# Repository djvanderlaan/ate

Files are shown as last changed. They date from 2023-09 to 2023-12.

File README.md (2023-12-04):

A⋅TE Portable Computers and Keyboards
========================================================

A⋅TE⋅B1
----------------------------------------------------

The [A⋅TE⋅B1](b1/) is an 3d-printed ortholinear keyboard with a
statisticians/programmers layout. The files are released under a [CC BY-SA
license](https://creativecommons.org/licenses/by-sa/4.0/).

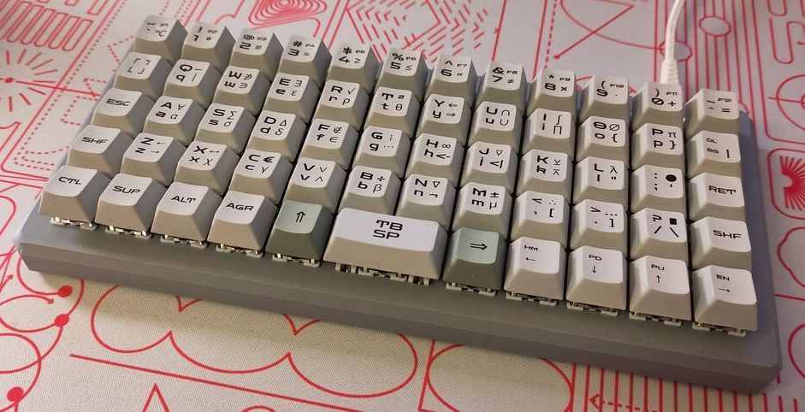
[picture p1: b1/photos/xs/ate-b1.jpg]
Photo of ATE-B1 keyboard


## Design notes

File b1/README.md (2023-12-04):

A⋅TE⋅B1 ortholinear keyboard
=====================================================

The [A⋅TE⋅B1](b1/) is an 3d-printed ortholinear keyboard with a
programmers/statisticians layout. The files are released under a [CC BY-SA
license](https://creativecommons.org/licenses/by-sa/4.0/).

Photo of ATE-B1 keyboard

Instructions
---------------------------------------------------------

Parts needed:

- 3d prints of the case and bottom
- Pro Micro controller. This build used a [Sparkfun Qwiic Pro Micro USB
  C](https://www.sparkfun.com/products/15795)
- 59 MX Switches and 2 stabilisers. This build used Gateron Keychron G Pro
  Yellow switches.
- 59 keycaps of which one 2 width keycap. In the build above existing keycaps
  were painted and labelled.
- 59 1N4148 diodes.
- 4 M2 screw inserts and 4 M2x8mm screws.

Tools needed:

- A soldering iron
- Wire stripper
- Some electric wire. For the columns solid core wire was used. To connect the
  rows and columns tot the controller stranded wire was used.

### Printing

The 3D print files are in the `stl/` directory. Both can be printed without
supports. The case should be printed upside down. The bottom bottom side down.
Supports are not needed. After printing two vertical supports in the slot that
holds the controller need to be removed (these are needed to be able to print
without supports). This can be done using an exacto knife and some prying. The
files are designed to fit a Prusa MK3s. 

Below are some photos of the case:

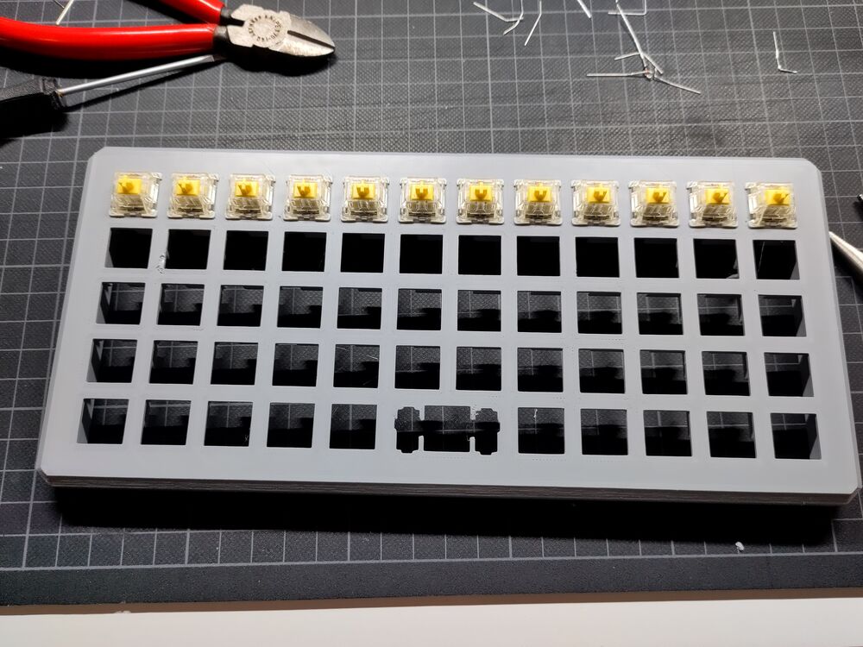
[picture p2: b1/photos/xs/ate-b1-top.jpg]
Photo of the top of the case with a few switches mounted


Photo of the bottom of the case with a few switches mounted

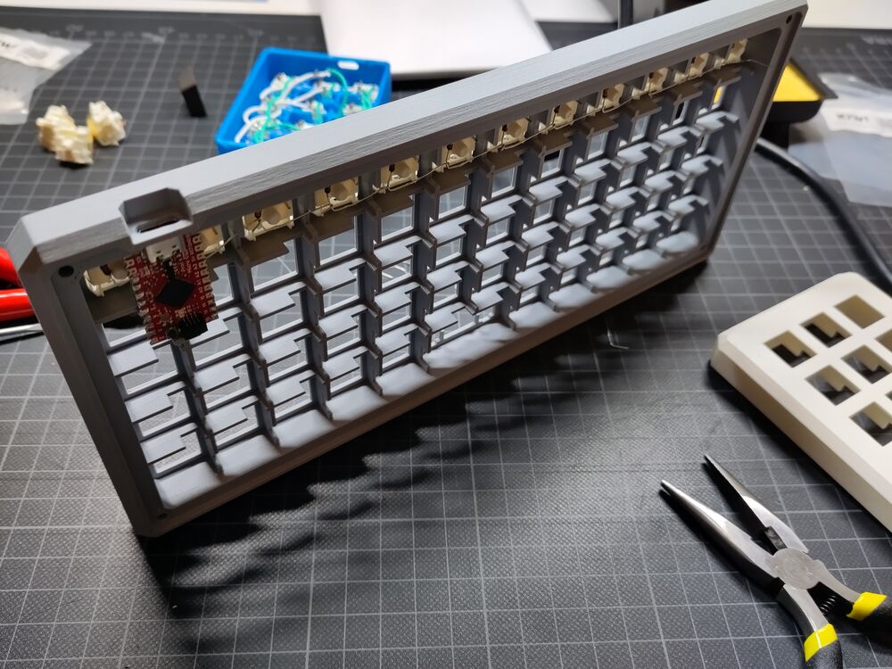
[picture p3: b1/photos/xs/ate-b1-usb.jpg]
Photo of the back of the case with the USB port


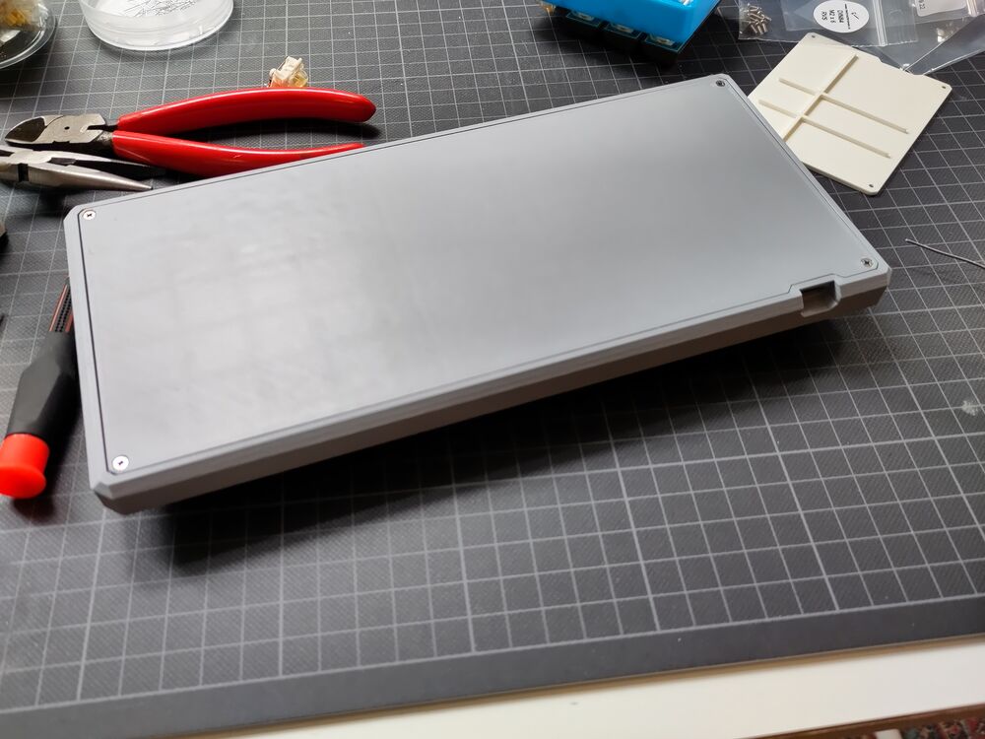
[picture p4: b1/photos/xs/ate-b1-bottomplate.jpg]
Photo of the back of the bottom plate


### Soldering

For general instructions see [A Complete Guide to Building a Hand-Wired Keyboard
by Ben
Chapman](https://www.crackedthecode.co/a-complete-guide-to-building-a-hand-wired-keyboard/) and
[the QMK guide on hand-wiring](https://docs.qmk.fm/#/hand_wire).  Below are
specific instructions for reproducing the build above and a picture of the
result:

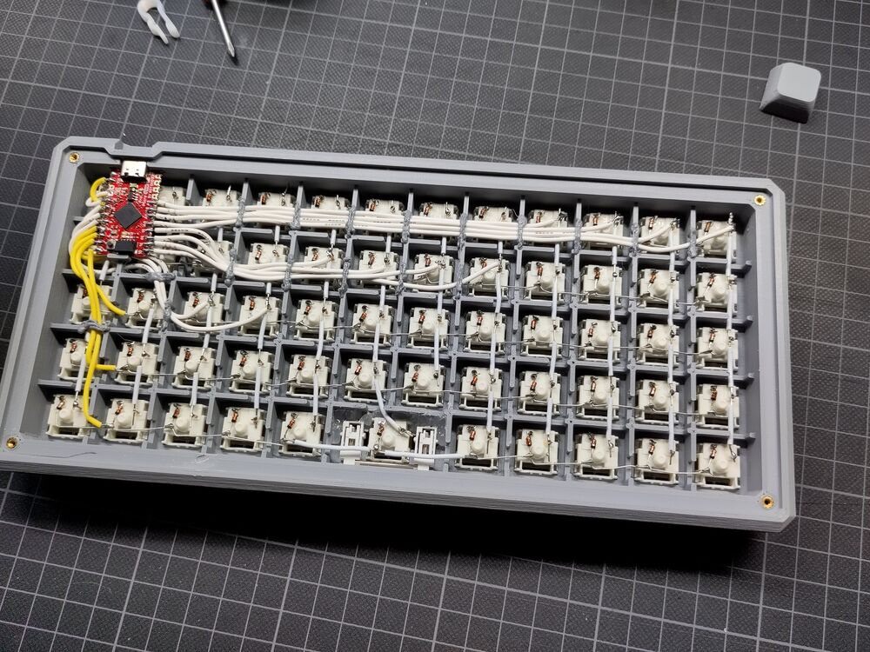
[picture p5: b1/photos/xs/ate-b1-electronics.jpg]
Photo of soldered electronics of the ATE-B1 keyboard


- For the rows the legs of the diodes were bent around each other and soldered
  together.
- Note that the spacebar is connected to column 6 (starting from 0). 
- For the columns an insulated wire was used where the insulation was removed at
  the points where it needed to be soldered to the switches. The easiest way to
  do this is to cut the insulation using a wire stripper and then push the
  insulation down the wire.

*TODO: wiring scheme for the controller*

### Programming the controller

First, follow [the instructions](https://docs.qmk.fm/#/newbs_getting_started) to
set up QMK. The git repository contains the keyboard configuration for the
A⋅TE⋅B1 under `qmk/`. Copy the contents of this directory to the
`keyboards/` directory under QMK or make a symbolic link (under linux).

Note the code assumes that the controller is wired as above and that the same
controller is used. If that is not the case the configuration has to be modified
to reflect the differences.

You should now be able to do:
```
qmk compile -kb ate_b1 -km default
```

Should this work you can do
```
qmk flash -kb ate_b1 -km default
```
to flash the controller. Follow the onscreen instructions. To get the controller
into flash mode you will have to press the reset button one the controller twice
in quick succession.

And then the keyboard should work. 

### Key caps

For the key caps of this build existing key caps were used. The were given a
thorough sanding with 280 grit sand paper. The two coats of gray primer (Vallejo
airbrush primer) and two coats of silver gray (Vallejo) using a air brush. The
labels were printed on 12µm transparent water slide decal paper (svg file is in
the repo). Some tips for this: use rounded corners and use a small stiff flat
brush to smoothen the decal on the key cap. After that the keys were varnished
using 4 layers of satin varnish (Vallejo).

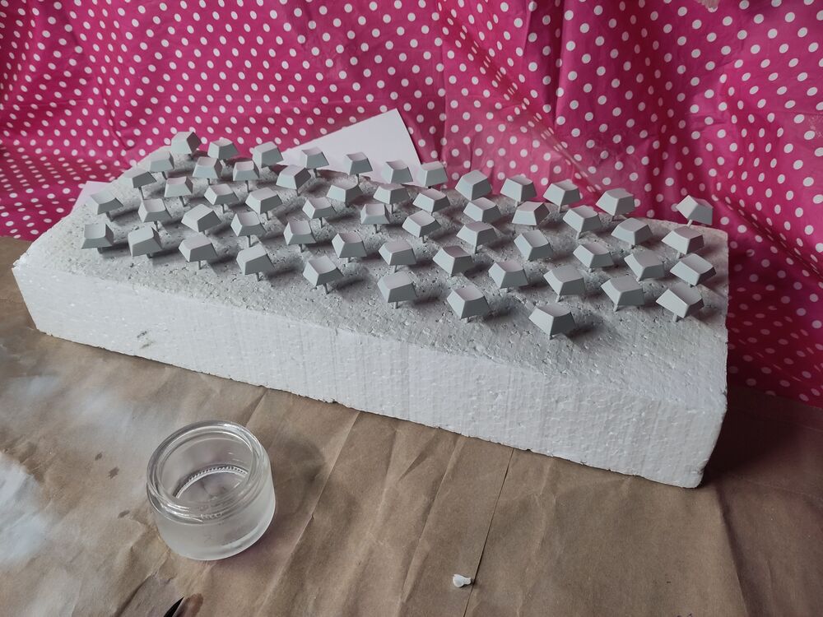
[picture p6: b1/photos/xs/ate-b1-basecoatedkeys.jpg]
Photo key caps with a base coat


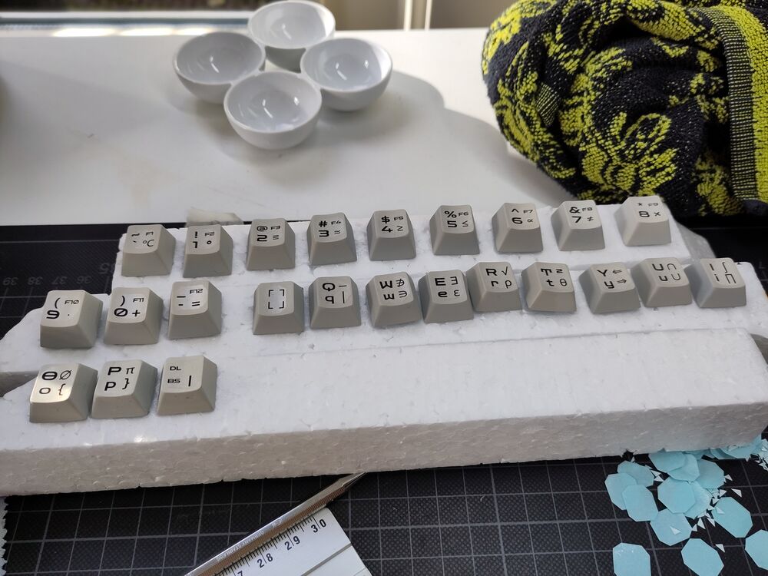
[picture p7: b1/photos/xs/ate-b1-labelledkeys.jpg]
Photo key caps with a labels


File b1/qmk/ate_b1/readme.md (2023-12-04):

# ate-b1

ate_b1

*A short description of the keyboard/project*

* Keyboard Maintainer: [djvanderlaan](https://github.com/djvanderlaan)
* Hardware Supported: *The PCBs, controllers supported*
* Hardware Availability: *Links to where you can find this hardware*

Make example for this keyboard (after setting up your build environment):

    make ate_b1:default

Flashing example for this keyboard:

    make ate_b1:default:flash

See the [build environment setup](https://docs.qmk.fm/#/getting_started_build_tools) and the [make instructions](https://docs.qmk.fm/#/getting_started_make_guide) for more information. Brand new to QMK? Start with our [Complete Newbs Guide](https://docs.qmk.fm/#/newbs).

## Bootloader

Enter the bootloader in 3 ways:

* **Bootmagic reset**: Hold down the key at (0,0) in the matrix (usually the top left key or Escape) and plug in the keyboard
* **Physical reset button**: Briefly press the button on the back of the PCB - some may have pads you must short instead
* **Keycode in layout**: Press the key mapped to `QK_BOOT` if it is available

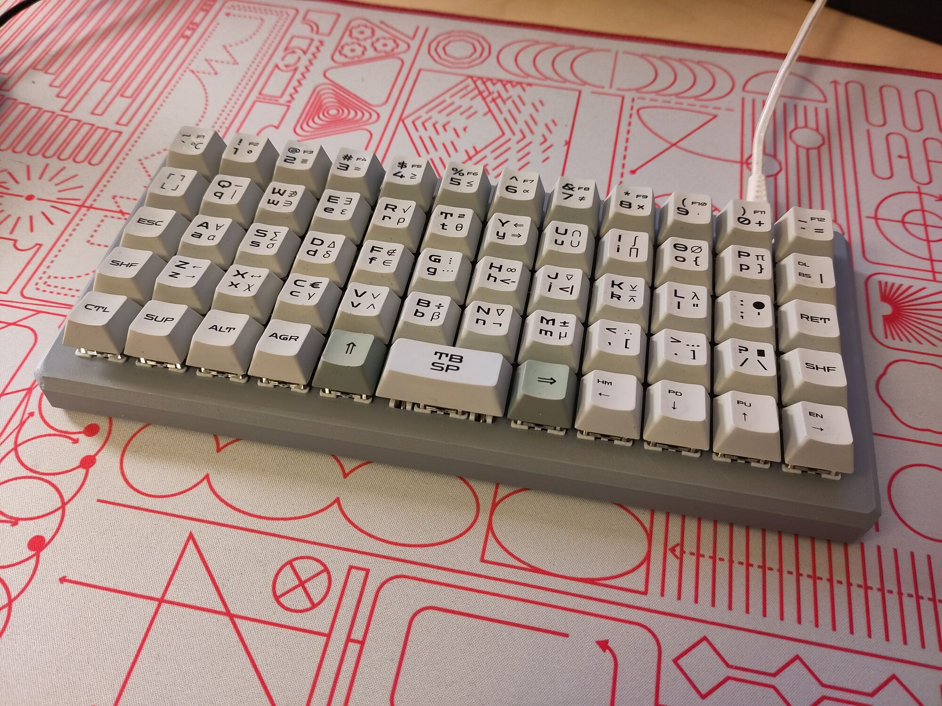
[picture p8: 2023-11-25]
b1/photos/s/ate-b1-finished2.jpg

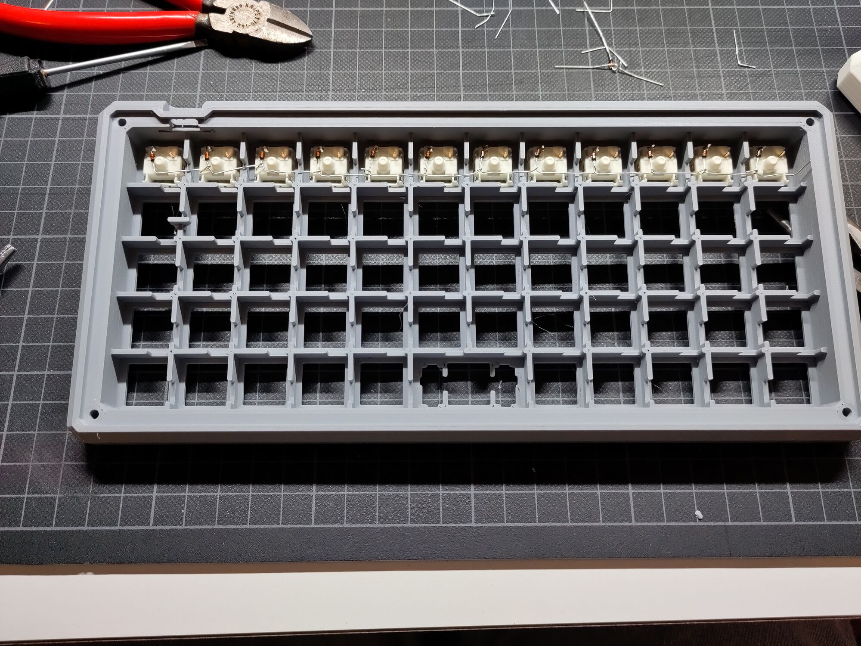
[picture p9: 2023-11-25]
b1/photos/s/ate_b1_bottom.jpg

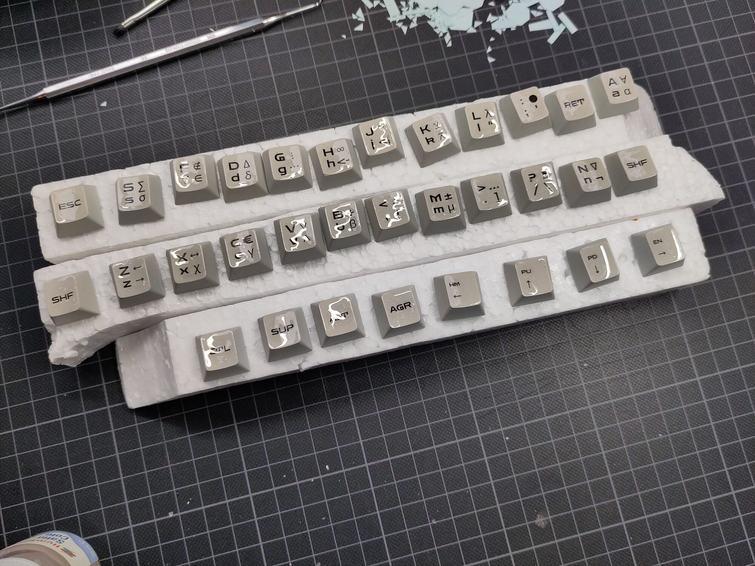
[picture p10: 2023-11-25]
b1/photos/s/ate-b1-coatedkeys.jpg

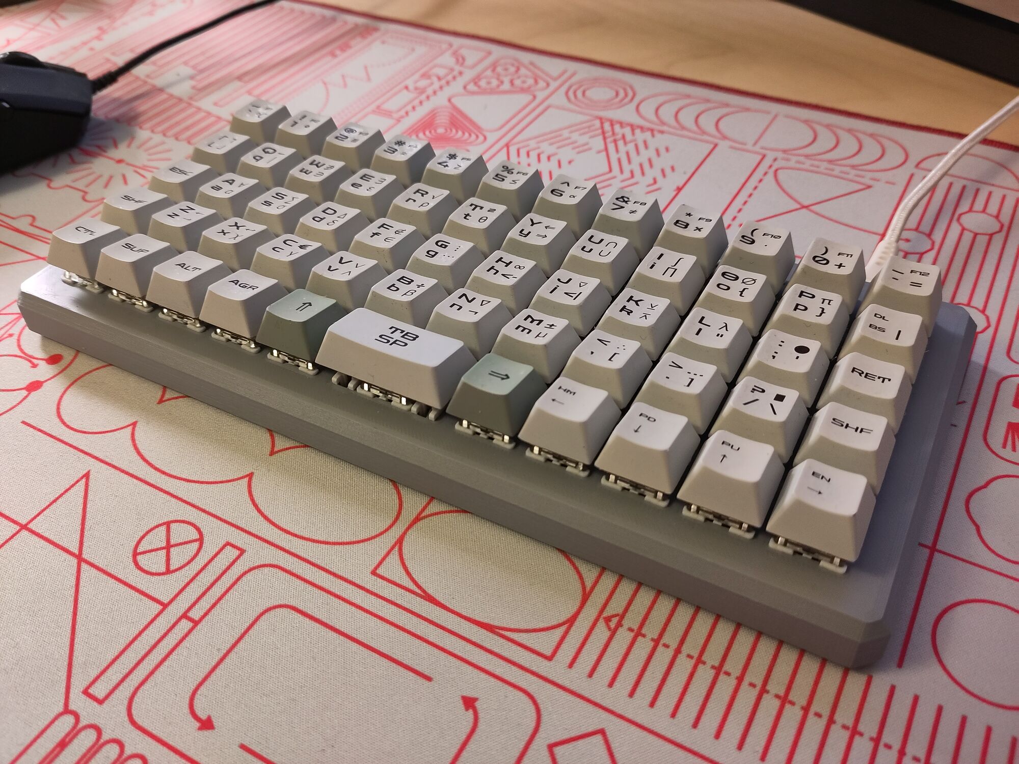
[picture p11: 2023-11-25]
b1/photos/s/ate-b1-finished.jpg

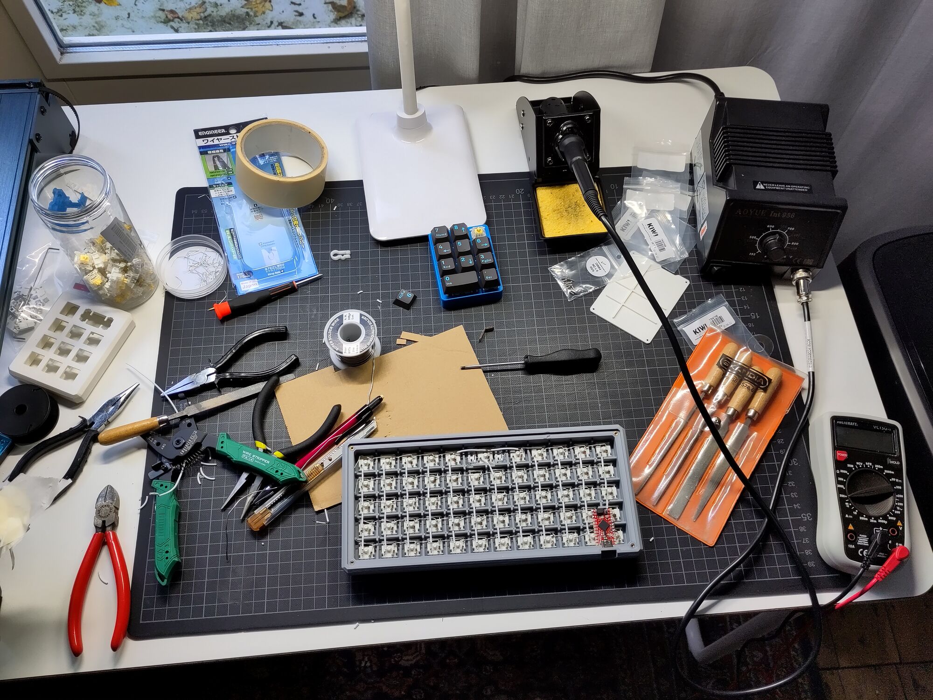
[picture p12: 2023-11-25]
b1/photos/s/ate-b1-desk.jpg

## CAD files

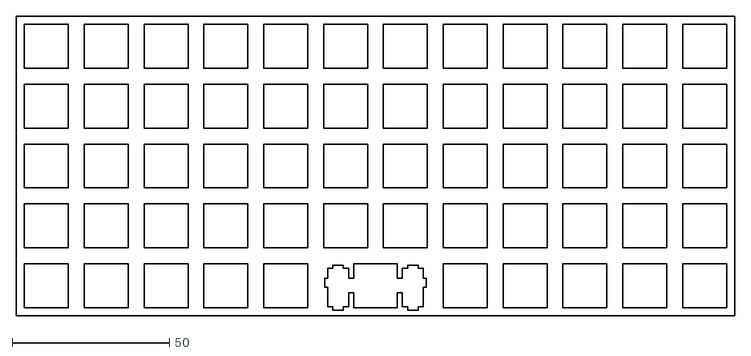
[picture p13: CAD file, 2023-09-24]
b1/sources/plate_base.dxf
228.6 x 95.2

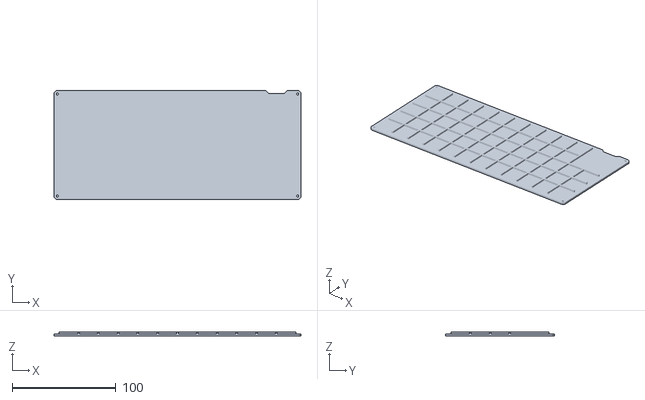
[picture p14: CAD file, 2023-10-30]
b1/stl/ate-b1-bottom-v1.0.stl
238.0 x 104.7 x 4.01

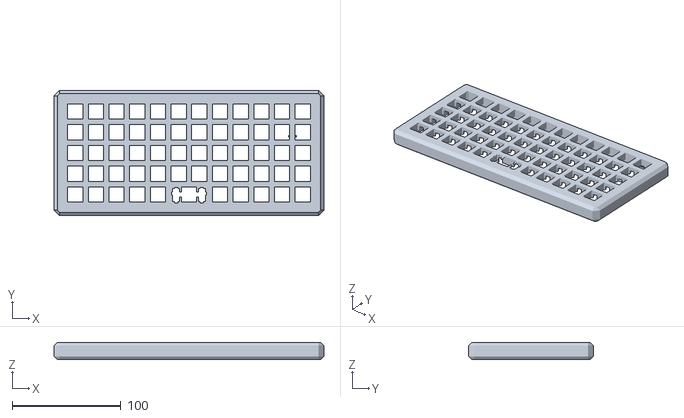
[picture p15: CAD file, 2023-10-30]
b1/stl/ate-b1-case-v1.0.stl
248.6 x 115.2 x 15.7

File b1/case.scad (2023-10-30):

$fn=100;
mar = 0.01;

// == Parameters of plate
plate_grid        = 19.05;
plate_thickness   = 1.45;
plate_nwidth      = 12;
plate_nlength     = 5;
plate_width       = plate_grid*plate_nwidth;
plate_length      = plate_grid*plate_nlength;

// == Parameters for switches
// https://switches-sensors.zf.com/wp-content/uploads/2012/07/Keymodule_MX_EN.pdf
switch_depth      = 5;
switch_pinlength  = 3.3;
switch_stick_out  = switch_depth+switch_pinlength - plate_thickness;

// == Parameters of outer case
case_pad          = 2*10;
case_width        = plate_width + case_pad;
case_length       = plate_length + case_pad;
case_height       = 15.74;
case_bevel_top    = 3;
case_bevel_corner = 5;
case_bevel_bottom = 3;
case_bevel_inner  = 2;
case_usb_inset    = 20;

// == Parameters for raster
raster_height     = 5-1.5;
raster_width      = 1.5;
raster_skip       = 6;

// == Parameters for guides
guide_width       = raster_width;
guide_height      = switch_stick_out + 1;
guide_left        = plate_grid*0.6;
guide_right       = plate_grid*0.1;
guide_top         = plate_grid*0.5;
guide_bottom      = plate_grid*0.15;

// == Parameters for bottom
bottom_thickness  = 2;
bottom_inset      = bottom_thickness;
bottom_edge       = 5;
bottom_mar        = 0.3;
bottom_raster     = 2;

// == Parameters for controler and USB port
controller_row     = plate_nwidth-1;
controller_depth   = 2.5;
controller_base    = 0.9;
controller_wall    = 2;
controller_width   = micropro_width()+1;
controller_height  = controller_base+0.5;
controller_support = 0.8;
controller_length  = 31.6;

use<scad/beveled_cube.scad>
use<scad/micropro_example.scad>
use<scad/rounded_cube.scad>

case = false;
bottom = true;

// how far does switch stick out at the back of the plate:
// https://switches-sensors.zf.com/wp-content/uploads/2012/07/Keymodule_MX_EN.pdf
// 5 mm thickness swith
// 3.3 mm length pins
// -1.5 thickness plate
// 5 + 3.3 - 1.5


if (case) {

// === TOP PLATE
color("red")
linear_extrude(plate_thickness)
  translate([-0.0947, -0.2578])
  import("sources/plate_base.dxf", convexity = 10);
  
// === CASE
translate([(plate_width)/2, plate_length/2, -case_height+plate_thickness])
difference() {
  // outside of case
  beveled_cube([case_width, case_length, case_height], 
      [case_bevel_top,case_bevel_top], case_bevel_corner, 
      [case_bevel_bottom, case_bevel_bottom]);
  // cut out central cube (where the plate is)
  translate([0, 0, -1])
    beveled_cube([plate_width-2*mar, plate_length-2*mar, case_height+2],
      [0.1, 0.1], case_bevel_inner, [0.1,0.1]);  
  // cut-out for bottom
  translate([0, 0, -mar])
    beveled_cube([plate_width+2*bottom_edge, plate_length+2*bottom_edge, bottom_inset+mar],
      [0, 0], case_bevel_inner, [0,0]);
  // cutout for USB-port 
  translate(-[(plate_width)/2, plate_length/2, -case_height+plate_thickness])
  translate([controller_row*plate_grid, plate_length+controller_depth+controller_wall, 
      -usb_hole_height()-guide_height-controller_base])
    translate([0, 0, 3.5/2])
    usb_hole(20, 10, 20);
  // cutout for usb port on controller
  translate(-[(plate_width)/2, plate_length/2, -case_height+plate_thickness])
  translate([controller_row*plate_grid-usb_width()/2, plate_length+controller_depth-case_pad, 
      -case_height-guide_height])
    cube([usb_width(), case_pad, case_height]);
  // cutout for the board of the controller
  // we leave a few part with width controller_support; otherwise the printer is 
  // unable to print the top of the hole as this is then not supported
  conthw = (controller_width-usb_width())/2;
  translate(-[(plate_width)/2, plate_length/2, -case_height+plate_thickness])
  translate([controller_row*plate_grid-controller_width/2, plate_length-2*mar, -guide_height])
    mirror([0, 0, 1])
    cube([conthw-controller_support, controller_depth+mar, controller_height]);
  translate(-[(plate_width)/2, plate_length/2, -case_height+plate_thickness])
  translate([controller_row*plate_grid-conthw+controller_width/2+controller_support, 
        plate_length-2*mar, -guide_height])
    mirror([0, 0, 1])
    cube([conthw-controller_support, controller_depth+mar, controller_height]);
  // holes for the screws to fix the bottom plate
  translate([(plate_width/2+bottom_edge/2-1), (plate_length/2+bottom_edge/2-1), bottom_inset-mar])
    cylinder(r = 3.2/2, h = 8);
  translate([(plate_width/2+bottom_edge/2-1), -(plate_length/2+bottom_edge/2-1), bottom_inset-mar])
    cylinder(r = 3.2/2, h = 8);
  translate([-(plate_width/2+bottom_edge/2-1), (plate_length/2+bottom_edge/2-1), bottom_inset-mar])
    cylinder(r = 3.2/2, h = 8);
  translate([-(plate_width/2+bottom_edge/2-1), -(plate_length/2+bottom_edge/2-1), bottom_inset-mar])
    cylinder(r = 3.2/2, h = 8);
}


// Inset for USB-port
// at the bottom below the usb port the rim in the case for the bottom plate
difference() {
  translate([controller_row*plate_grid, plate_length+bottom_edge+mar, -case_height+plate_thickness])
  mirror([0, 1, 0])
  union(){
    //cube([case_usb_inset, bottom_edge-controler_depth+mar, bottom_inset+mar]);
    translate([-mar, 0, 0])
      bevels([case_usb_inset/2+mar, bottom_edge-controller_depth+mar, bottom_inset+mar], 
        0, bottom_edge- controller_depth+mar);
    mirror([1, 0, 0]) 
      bevels([case_usb_inset/2, bottom_edge-controller_depth+mar, bottom_inset+mar], 
        0, bottom_edge-controller_depth+mar);
  }
  // cutout for USB
  translate([controller_row*plate_grid, plate_length+controller_depth+controller_wall, 
      -usb_hole_height()-guide_height-controller_base])
    translate([0, 0, 3.5/2])
      usb_hole(20, 10, 20);
}


// === RASTER
// Raster in x/width direction
for (i = [1:(plate_nlength-1)]) {
  translate([-mar, i*plate_grid-raster_width/2, -raster_height])
    cube([plate_width+2*mar, raster_width, raster_height+mar]);
}
// Raster in y/length direction
for (i = [1:(plate_nwidth-1)]) {
  if (i == raster_skip) {
    translate([i*plate_grid-raster_width/2, -mar+plate_grid, -raster_height])
      cube([raster_width, plate_length+2*mar-plate_grid, raster_height+mar]);
  } else {
    translate([i*plate_grid-raster_width/2, -mar, -raster_height])
      cube([raster_width, plate_length+2*mar, raster_height+mar]);
  }
}

// === GUIDES
// Guides in x/width direction
for (j = [1:(plate_nlength-1)]) for (i = [1:(plate_nwidth)]) {
  // Left part of guide
  translate([i*plate_grid-guide_left+mar, j*plate_grid-guide_width/2, -guide_height])
    cube([guide_left+mar, guide_width, guide_height+mar]);
  // Right part 
  translate([i*plate_grid-plate_grid-mar, j*plate_grid-guide_width/2, -guide_height])
    cube([guide_right+mar, guide_width, guide_height+mar]);
}
// Guides in y/length direction
for (j = [1:(plate_nlength)]) for (i = [1:(plate_nwidth-1)]) {
  if (j != 1 || i != raster_skip) {
    // Top part of guide
    translate([i*plate_grid-guide_width/2, j*plate_grid-guide_top+mar, -guide_height])
      cube([guide_width, guide_top+mar, guide_height+mar]);
    // Bottom part of guide
    translate([i*plate_grid-guide_width/2, (j-1)*plate_grid-mar, -guide_height])
      cube([guide_width, guide_bottom+mar, guide_height+mar]);
  }
}

// === STOPPER FOR CONTROLER
translate([controller_row*plate_grid, plate_length-guide_width-controller_length, 
    -raster_height+mar])
  mirror([0, 0, 1])
  tapered_cube(guide_width, 7, guide_height-raster_height+controller_depth, guide_width);
translate([controller_row*plate_grid-guide_width/2, plate_length-5-controller_length, 
    -guide_height])
  mirror([0, 0, 0])
  cube([guide_width, 5, guide_width]);



} //end case
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

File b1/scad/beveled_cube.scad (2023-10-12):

// Beveled cube
//
// dim: dimensions of the cube
// bevel_top: 2d array width the dimensions of the bevel used
//   at the top of the cube. The first element specifies the 
//   amount the bevel goed towards the z-axis. The second
//   element the height of the bevel.
// bevel_size: single value with the dimension of the side 
//   bevel
// bevel_bottom: 2d array for the bottom bevel. See 
//   bevel_top. 
//
// The cube is centered at the origin for the x and y axis and 
// the bottom of the cube is positioned at z=0. 
// 
// Example:
 dim = [200, 100, 20];
 bevel_top  = [10, 3];
 bevel_side  = 8;
 bevel_bottom  = [4, 4];
 beveled_cube(dim, bevel_top, bevel_side, bevel_bottom);

module beveled_cube(dim, bevel_top, bevel_side, bevel_bottom) {
  mar = 0.01;
  d = [dim[0]*0.5+mar, dim[1]*0.5+mar, dim[2]];
  translate([-mar, -mar, 0])
    beveled_cube_q(d, bevel_top, bevel_side, bevel_bottom);
  mirror([1, 0, 0])
    translate([-mar, -mar, 0])
    beveled_cube_q(d, bevel_top, bevel_side, bevel_bottom);
  mirror([0, 1, 0])
    translate([-mar, -mar, 0])
    beveled_cube_q(d, bevel_top, bevel_side, bevel_bottom);
  mirror([1, 0, 0]) mirror([0, 1, 0])
    translate([-mar, -mar, 0])
    beveled_cube_q(d, bevel_top, bevel_side, bevel_bottom);
}

// Utility function for beveled_cube
module beveled_cube_q(dim, bt, bs, bb) {
  mar = 0.01;
  // top
  translate([0, 0, dim[2]-bt[1]])
    bevels([dim[0], dim[1], bt[1]], bt[0], bs);
  // middle
  translate([0, 0, bb[1]-mar])
    bevels([dim[0], dim[1], dim[2]-bt[1]-bb[1]+2*mar], 0, bs);
  //bottom
  translate([0, 0, bb[1]])
    mirror([0, 0, 1])
    bevels([dim[0], dim[1], bb[1]], bb[0], bs);
}

// Utility function for beveled_cube
module bevels(dim, bt, bs) {
  polyhedron(
    points = [
      [0, 0, 0], // 0
      [dim[0], 0, 0], // 1
      [dim[0]-bt, 0, dim[2]], // 2
      [0, 0, dim[2]],  // 3
      [dim[0], dim[1]-bs, 0], //4 
      [dim[0]-bt, min(dim[1]-bt, dim[1]-bs), dim[2]], //5
      [0, dim[1], 0],  // 6
      [dim[0]-bs, dim[1], 0], //7 
      [min(dim[0]-bt, dim[0]-bs), dim[1]-bt, dim[2]], //8
      [0, dim[1]-bt, dim[2]] //9
    ],
    faces = [
      [3, 9, 8, 5, 2], //top
      [0, 3, 2, 1], //front
      [0, 6, 9, 3], //left 
      [6, 7, 8, 9], // back
      [7, 4, 5, 8], // back-side-bevel
      [1, 2, 5, 4], // right side
      [0, 1, 4, 7, 6] // bottom
    ]
  );
}

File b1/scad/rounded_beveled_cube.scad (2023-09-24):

use<rounded_cube.scad>

module bevel_base(width, height, offset = 0) {
  if (offset > 0) {
    polygon([ [0, 0], [offset + width, 0], [offset, height], [0, height] ]);
  } else {
    polygon([ [0, 0], [width, 0], [0, height] ]);
  }
}

module top_quart(width, height, radius, bevel) {
  translate([width*0.5-radius, height*0.5-radius])
    rotate_extrude(angle = 90)
    bevel_base(bevel[0], bevel[1], offset = radius - bevel[0]);
  translate([width*0.5-radius, height*0.5-radius])
    rotate([90, 0, 0])
    linear_extrude(height*0.5-radius)
    bevel_base(bevel[0], bevel[1], offset = radius - bevel[0]);
  translate([0, height*0.5-radius])
    rotate([90, 0, 90])
    linear_extrude(width*0.5-radius)
    bevel_base(bevel[0], bevel[1], offset = radius - bevel[0]);
  cube([width*0.5-radius, height*0.5-radius, bevel[1]]);
}

module top(width, height, radius, bevel) {
  top_quart(width, height, radius, bevel);
  mirror([1,0,0]) top_quart(width, height, radius, bevel);
  mirror([0,1,0]) top_quart(width, height, radius, bevel);
  mirror([0,1,0]) mirror([1,0,0]) top_quart(width, height, radius, bevel);
}

module rounded_beveled_cube(dim, radius, bevel_top, bevel_bottom) {
  translate([0, 0, dim[2]-bevel_top[1]])
    top(dim[0], dim[1], radius, bevel_top);
  translate([0, 0, bevel_bottom[1]])
    rounded_cube([dim[0], dim[1], dim[2]-bevel_top[1]-bevel_bottom[1]], radius);
  translate([0, 0, bevel_bottom[1]])
    mirror([0, 0, 1])
    top(dim[0], dim[1], radius, bevel_bottom);
}

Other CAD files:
b1/scad/rounded_cube.scad
b1/scad/micropro_example.scad

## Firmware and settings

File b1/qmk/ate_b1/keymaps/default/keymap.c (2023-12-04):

#include QMK_KEYBOARD_H



enum custom_keycodes {
  RARROW = SAFE_RANGE,
  RPIPE
};

/*
const uint16_t PROGMEM keymaps[][MATRIX_ROWS][MATRIX_COLS] = {
	[0] = LAYOUT(
          KC_GRAVE, KC_1,       KC_2,       KC_3,       KC_4,       KC_5,       KC_6,       KC_7,       KC_8,       KC_9,       KC_0,       KC_MINS, 
          KC_TAB,   KC_Q,       KC_W,       KC_E,       KC_R,       KC_T,       KC_Y,       KC_U,       KC_I,       KC_O,       KC_P,       KC_BSPC, 
          KC_ESC,   KC_A,       KC_S,       KC_D,       KC_F,       KC_G,       KC_H,       KC_J,       KC_K,       KC_L,       KC_SCLN,    KC_ENT, 
          KC_LSFT,  KC_Z,       KC_X,       KC_C,       KC_V,       KC_B,       KC_N,       KC_M,       KC_COMM,    KC_DOT,     KC_SLSH,    KC_RSFT, 
          KC_LCTL,  KC_LGUI,    KC_LALT,    KC_ALGR,    MO(1),      KC_SPC,                 MO(2),      KC_LEFT,    KC_DOWN,    KC_UP,      KC_RGHT),
        [1] = LAYOUT(
          KC_TILD,  KC_EXLM,    KC_AT,      KC_HASH,    KC_DLR,     KC_PERC,    KC_CIRC,    KC_AMPR,    KC_ASTR,    KC_LPRN,    KC_RPRN,    KC_UNDS,
          _______,  LSFT(KC_Q), LSFT(KC_W), LSFT(KC_E), LSFT(KC_R), LSFT(KC_T), LSFT(KC_Y), LSFT(KC_U), LSFT(KC_I), LSFT(KC_O), LSFT(KC_P), KC_DEL,
          _______,  LSFT(KC_A), LSFT(KC_S), LSFT(KC_D), LSFT(KC_F), LSFT(KC_G), LSFT(KC_H), LSFT(KC_J), LSFT(KC_K), LSFT(KC_L), _______,    _______,
          _______,  LSFT(KC_Z), LSFT(KC_X), LSFT(KC_C), LSFT(KC_V), LSFT(KC_B), LSFT(KC_N), LSFT(KC_M), _______,    _______,    _______,    _______,
          _______,  _______,    _______,    _______,    _______,    KC_TAB,                 MO(3),      KC_HOME,    KC_PGDN,    KC_PGUP,    KC_END),
        [2] = LAYOUT(
          UC(0x2103), UC(0x00B0), UC(0x2261), _______, _______, _______, _______, _______, _______, _______, KCPLUS,  KC_PEQL,
          _______,  _______,    _______, _______, _______, _______, _______, _______, _______, _______, _______, _______,
          _______,  UC(0x03B1), _______, _______, _______, _______, _______, _______, _______, _______, _______, _______,
          _______,  _______,    _______, _______, _______, _______, _______, _______, _______, _______, _______, _______,
          _______,  _______,    _______, _______, MO(3),   _______,          _______, _______, _______, _______, _______),
        [3] = LAYOUT(
          _______,  _______,    _______, _______, _______, _______, _______, _______, _______, _______, _______, _______,
          _______,  _______,    _______, _______, _______, _______, _______, _______, _______, _______, _______, _______,
          QK_UNICODE_MODE_NEXT,  UC(0x2200), _______, _______, _______, _______, _______, _______, _______, _______, _______, _______,
          _______,  _______,    _______, _______, _______, _______, _______, _______, _______, _______, _______, _______,
          _______,  _______,    _______, _______, _______, _______,          _______, _______, _______, _______, _______)
};
*/


const uint16_t PROGMEM keymaps[][MATRIX_ROWS][MATRIX_COLS] = {
  [0] = LAYOUT(
    KC_GRV    , KC_1      , KC_2      , KC_3      , KC_4      , KC_5      , KC_6      , KC_7      , KC_8      , KC_9      , KC_0      , KC_MINS   , 
    UC(0x2514), KC_Q      , KC_W      , KC_E      , KC_R      , KC_T      , KC_Y      , KC_U      , KC_I      , KC_O      , KC_P      , KC_BSPC   , 
    KC_ESC    , KC_A      , KC_S      , KC_D      , KC_F      , KC_G      , KC_H      , KC_J      , KC_K      , KC_L      , KC_SCLN   , KC_ENT    , 
    KC_LSFT   , KC_Z      , KC_X      , KC_C      , KC_V      , KC_B      , KC_N      , KC_M      , KC_COMM   , KC_DOT    , KC_SLSH   , KC_RSFT   , 
    KC_LCTL   , KC_LGUI   , KC_LALT   , KC_ALGR   , MO(1)     , KC_SPC                , MO(2)     , KC_LEFT   , KC_DOWN   , KC_UP     , KC_RIGHT  ),
  [1] = LAYOUT(
    KC_TILD   , KC_EXLM   , KC_AT     , S(KC_3)   , KC_DLR    , KC_PERC   , KC_CIRC   , KC_AMPR   , KC_ASTR   , KC_LPRN   , KC_RPRN   , KC_UNDS   , 
    UC(0x250c), S(KC_Q)   , S(KC_W)   , S(KC_E)   , S(KC_R)   , S(KC_T)   , S(KC_Y)   , S(KC_U)   , S(KC_I)   , S(KC_O)   , S(KC_P)   , KC_DEL    , 
    _______   , S(KC_A)   , S(KC_S)   , S(KC_D)   , S(KC_F)   , S(KC_G)   , S(KC_H)   , S(KC_J)   , S(KC_K)   , S(KC_L)   , KC_COLN   , _______   , 
    _______   , S(KC_Z)   , S(KC_X)   , S(KC_C)   , S(KC_V)   , S(KC_B)   , S(KC_N)   , S(KC_M)   , KC_LABK   , KC_RABK   , KC_QUES   , _______   , 
    _______   , _______   , _______   , _______   , _______   , KC_TAB                , MO(3)     , KC_HOME   , KC_PGDN   , KC_PGUP   , KC_END    ),
  [2] = LAYOUT(
    UC(0x2103), UC(0x00b0), UC(0x2261), UC(0x2248), UC(0x2265), UC(0x2264), UC(0x221d), UC(0x2260), UC(0x00d7), UC(0x22c5), KC_PLUS   , KC_EQL    , 
    UC(0x2518), UC(0x2502), UC(0x220b), UC(0x03b5), UC(0x03c1), UC(0x03b8), UC(0x21d2), UC(0x222a), UC(0x220f), KC_LCBR   , KC_RCBR   , KC_PIPE   , 
    _______   , UC(0x03b1), UC(0x03c3), UC(0x03b4), UC(0x2208), UC(0x22ef), RARROW    , RPIPE     , UC(0x22bc), KC_DQUO   , KC_QUOT   , _______   , 
    _______   , UC(0x2192), UC(0x03c7), UC(0x03b3), UC(0x2227), UC(0x03b2), UC(0x00ac), UC(0x03bc), KC_LBRC   , KC_RBRC   , KC_BSLS   , _______   , 
    _______   , _______   , _______   , _______   , MO(3)     , _______               , _______   , _______   , _______   , _______   , _______   ),
  [3] = LAYOUT(
    KC_F1     , KC_F2     , KC_F3     , KC_F4     , KC_F5     , KC_F6     , KC_F7     , KC_F8     , KC_F9     , KC_F10    , KC_F11    , KC_F12    , 
    UC(0x2510), UC(0x2500), UC(0x220c), UC(0x2203), UC(0x221a), UC(0x00b2), UC(0x21d0), UC(0x2229), UC(0x222b), UC(0x2205), UC(0x03c0),           , 
    _______   , UC(0x2200), UC(0x2211), UC(0x0394), UC(0x2209), UC(0x22ee), UC(0x221e), UC(0x22bb), UC(0x22bd), UC(0x03bb), UC(0x25cf), _______   , 
    _______   , UC(0x2190), UC(0x2194), UC(0x20ac), UC(0x2228), UC(0x00f7), UC(0x2207), UC(0x00b1), UC(0x2234), UC(0x2026), UC(0x220e), _______   , 
    _______   , _______   , _______   , _______   , _______   , _______               , _______   , _______   , _______   , _______   , _______ )
};

bool process_record_user(uint16_t keycode, keyrecord_t* record) {
  switch (keycode) {
    case RARROW:
      if (record->event.pressed) {
        SEND_STRING("<-");
      }
      return false;
    case RPIPE:
      if (record->event.pressed) {
        SEND_STRING("|>");
      }
      return false;
  }
  return true;
}

#if defined(ENCODER_ENABLE) && defined(ENCODER_MAP_ENABLE)
const uint16_t PROGMEM encoder_map[][NUM_ENCODERS][NUM_DIRECTIONS] = {

};
#endif // defined(ENCODER_ENABLE) && defined(ENCODER_MAP_ENABLE)

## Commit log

2023-09-11 test0 '
    [plate_base.dxf, plate_t0.scad]
2023-09-18 test 0.1
    [case.scad, case_v0.1.stl]
2023-09-25 beveled cube
    [bc.scad]
2023-11-24 Renaming folders
    [ate_bottom_v1.0.stl, ate_v1.0.stl, beveled_cube.scad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]
